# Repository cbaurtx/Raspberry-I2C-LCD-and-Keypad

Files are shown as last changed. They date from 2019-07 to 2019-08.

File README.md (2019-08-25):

# Raspberry-I2C-LCD-and-Keypad
LCD Display and Keypad controller connected to Raspberry Pi via i2c
KiCAD (http://www.kicad-pcb.org) is used for schematics and PCB layout

Connection to the Raspberry Pi:

RasPi pin | Keypad / LCD Signal|Description
----------|--------------------|-----------
2|5V|power
3|SCL|serial clock
6|SDG|serial ground / shield
5|SDA|serial data
6|GND|ground
12|INT|interrupt

You can populate the PCB partially if only the LCD display or the keypad
controller is needed.

Blockdiagramm
Overview schematics

Raspberry interface
Raspberry interface

Display:
Display controller

Keypad:
Keypad controller

Created using KiCAD 5.1.3
Conceived using information from: https://5volt-junkie.net/i2c-keypad/

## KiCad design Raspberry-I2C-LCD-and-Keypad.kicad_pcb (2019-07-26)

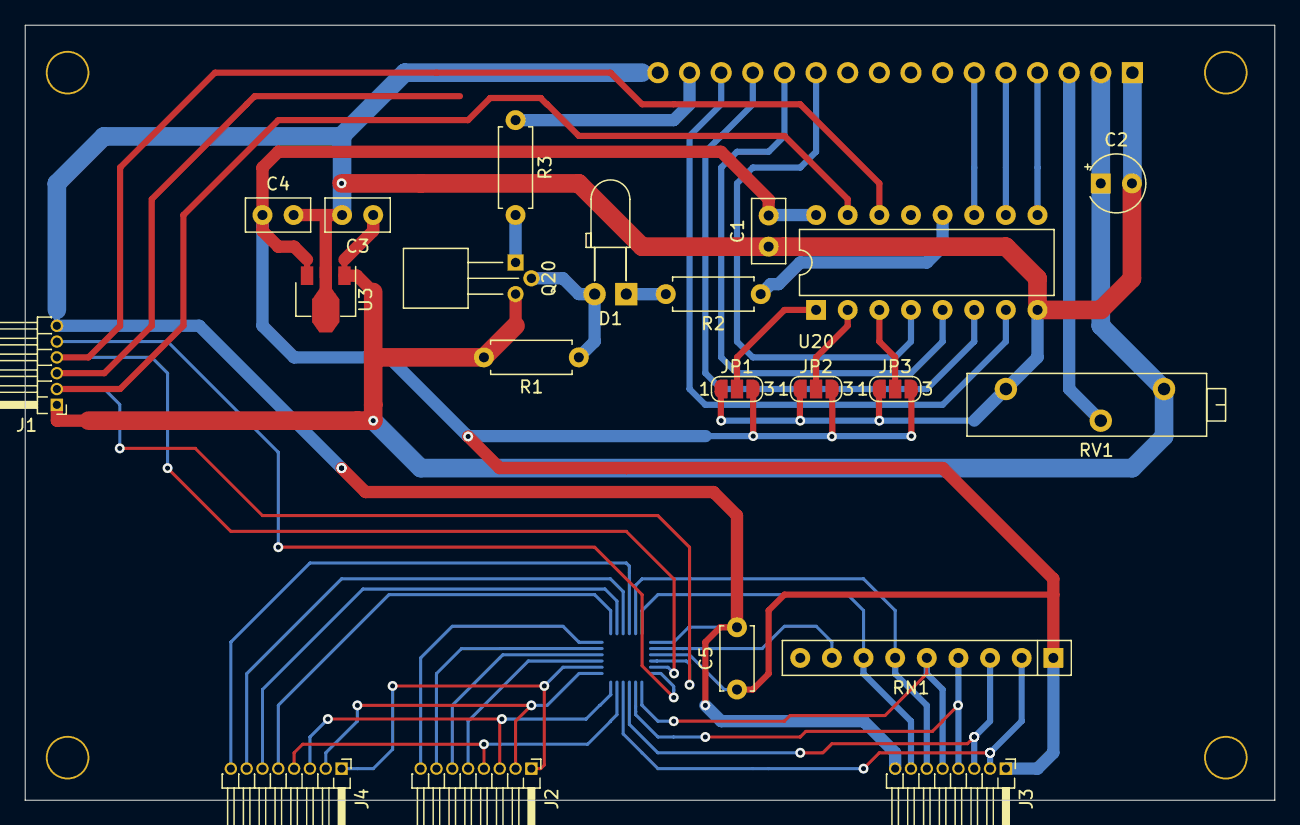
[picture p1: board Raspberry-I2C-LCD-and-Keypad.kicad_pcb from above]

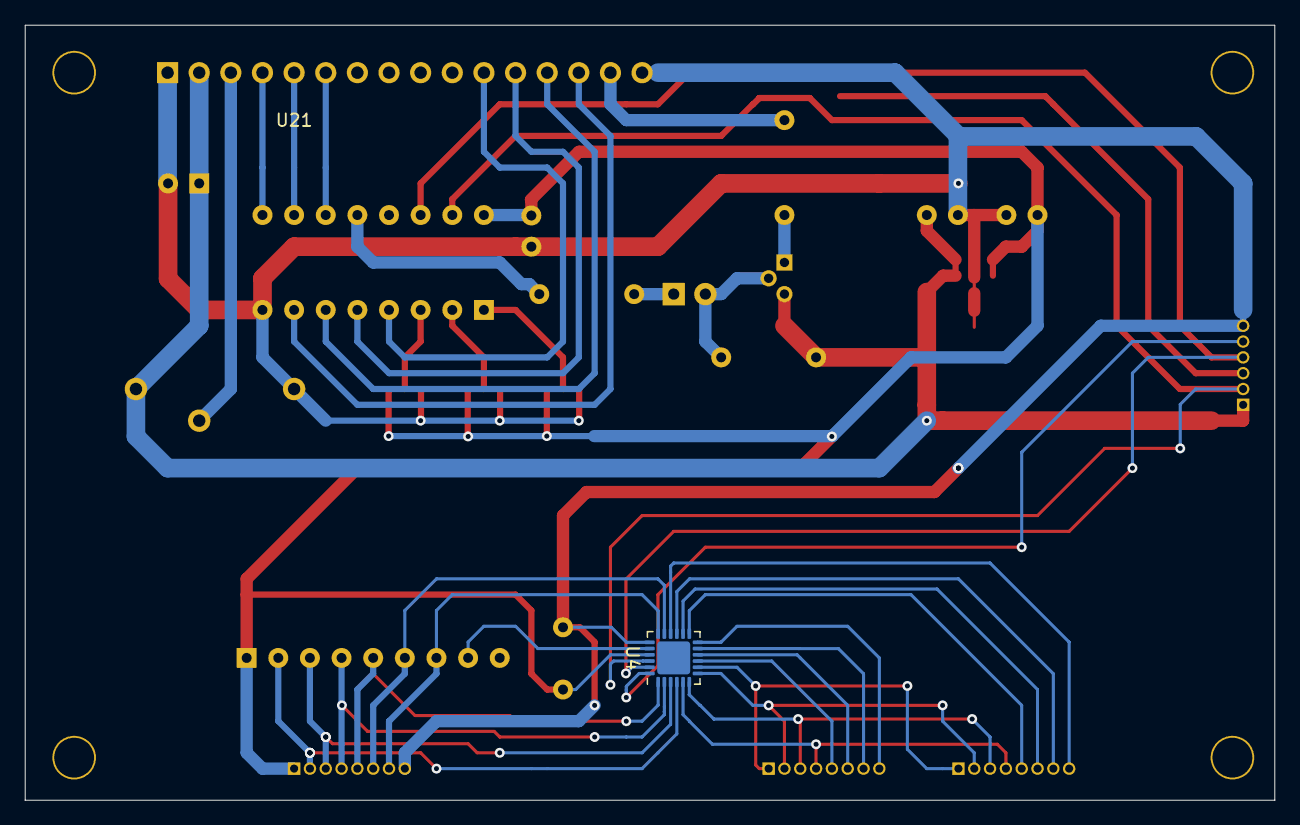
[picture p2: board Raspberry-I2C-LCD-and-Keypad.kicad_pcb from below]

Board: 2 copper layers, 100.3 x 62.2 mm, 23 parts (2 on the bottom side), 41 nets.

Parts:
C1, C3, C4: 100n; C_Disc_D5.0mm_W2.5mm_P2.50mm
C2: 10µ; CP_Radial_Tantal_D4.5mm_P2.50mm
C5: 100n; C_Disc_D5.0mm_W2.5mm_P5.00mm
D1: green; LED_D3.0mm_Horizontal_O3.81mm_Z2.0mm
J1: Conn_01x06; PinHeader_1x06_P1.27mm_Horizontal
J2, J3, J4: Conn_01x08; PinHeader_1x08_P1.27mm_Horizontal
JP1, JP2, JP3: Jumper_NC_Dual; SolderJumper-3_P1.3mm_Open_RoundedPad1.0x1.5mm_NumberLabels
Q20: BC557; TO-92_Horizontal1
R1: 4k7; R_Axial_DIN0207_L6.3mm_D2.5mm_P7.62mm_Horizontal
R2: 1k; R_Axial_DIN0207_L6.3mm_D2.5mm_P7.62mm_Horizontal
R3: 180; R_Axial_DIN0207_L6.3mm_D2.5mm_P7.62mm_Horizontal
RN1: 10k; R_Array_SIP9
RV1: 10k; Potentiometer_Vishay_43_Horizontal
U3: AP2204R-3.3; SOT-89-3
U4: TCA8418; QFN-24-1EP_4x4mm_P0.5mm_EP2.65x2.65mm
U20: PCF8574A; DIP-16_W7.62mm
U21: LCD_HD44780; QC2004A

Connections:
+3V3: C1.2, C4.1, C5.1, J3.1, JP1.3, JP2.3, JP3.3, RN1.1, U3.3, U4.21, U20.16
/DisplayController/5V: C2.1, C3.1, J1.1, Q20.3, R1.2, RV1.3, U3.1, U21.2
/DisplayController/GND: C1.1, C2.2, C3.2, C4.2, C5.2, J1.6, J3.8, JP1.1, JP2.1, JP3.1, RV1.1, U3.2, U4.19, U20.8, U21.1, U21.16
/DisplayController/SCL: J1.4, U4.23, U20.14
/DisplayController/SDA: J1.2, U4.22, U20.15
/KeypadController/~INT: J1.5, U4.24
/KeypadController/~RES: RN1.8, U4.20
unnamed: D1.1, R2.2
unnamed: D1.2, Q20.2, R1.1
unnamed: J2.1, J4.1, U4.8
unnamed: J2.2, J4.2, U4.7
unnamed: J2.3, J4.3, U4.6
unnamed: J2.4, J4.4, U4.5
unnamed: J2.5, U4.9
unnamed: J2.6, U4.10
unnamed: J2.7, U4.11
unnamed: J2.8, U4.12
unnamed: J3.2, RN1.2, U4.4
unnamed: J3.3, RN1.3, U4.3
unnamed: J3.4, RN1.4, U4.2
unnamed: J3.5, RN1.5, U4.1
unnamed: J3.6, RN1.6, U4.17
unnamed: J3.7, RN1.7, U4.18
unnamed: J4.5, U4.13
unnamed: J4.6, U4.14
unnamed: J4.7, U4.15
unnamed: J4.8, U4.16
unnamed: JP1.2, U20.1
unnamed: JP2.2, U20.2
unnamed: JP3.2, U20.3
unnamed: Q20.1, R3.2
unnamed: R2.1, U20.12
unnamed: R3.1, U21.15
unnamed: RV1.2, U21.3
unnamed: U20.4, U21.11
unnamed: U20.5, U21.12
unnamed: U20.6, U21.13
unnamed: U20.7, U21.14
unnamed: U20.9, U21.4
unnamed: U20.10, U21.5
unnamed: U20.11, U21.6

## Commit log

2019-07-25 new file: DisplayController.sch new file: KeypadController.sch new file: RasPiInterface.bck new file: RasPiInterface.dcm new file: RasPiInterface.lib new file: RasPiInterface.sch new file: Raspberry-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
    [DisplayController.sch, KeypadController.sch, RasPiInterface.sch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]
2019-07-26 modified: DisplayController.sch modified: KeypadController.sch new file: QC2004A.kicad_mod modified: RasPiInterface.lib modified: RasPiInterface.sch new file: Raspberry-I2C-LCD-and-Keypad-B_Cu.gbr ne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
    [DisplayController.sch, KeypadController.sch, RasPiInterface.sch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]
2019-07-26 modified: QC2004A.kicad_mod deleted: RasPiInterface.bck deleted: RasPiInterface.dcm modified: RasPiInterface.lib deleted: Raspberry-I2C-LCD-and-Keypad-B_Paste.gbr deleted: Raspberry-I2C-LCD-and-Keypa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
    [Raspberry-I2C-LCD-and-Keypad-B_Cu.gbr, Raspberry-I2C-LCD-and-Keypad-B_Mask.gbr, Raspberry-I2C-LCD-and-Keypad-Edge_Cuts.gbr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]
2019-07-26 modified: Raspberry-I2C-LCD-and-Keypad.kicad_pcb new file: build/Raspberry-I2C-LCD-and-Keypad-B_Cu.gbr new file: build/Raspberry-I2C-LCD-and-Keypad-B_Mask.gbr new file: build/Raspberry-I2C-LCD-and-Ke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
    [Raspberry-I2C-LCD-and-Keypad-B_Cu.gbr, Raspberry-I2C-LCD-and-Keypad-B_Mask.gbr, Raspberry-I2C-LCD-and-Keypad-B_Paste.gbr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]
2019-07-26 deleted: Raspberry-I2C-LCD-and-Keypad.kicad_pcb-bak
2019-07-26 deleted: build/Raspberry-I2C-LCD-and-Keypad-B_Cu.gbr deleted: build/Raspberry-I2C-LCD-and-Keypad-B_Mask.gbr deleted: build/Raspberry-I2C-LCD-and-Keypad-F_Cu.gbr deleted: build/Raspberry-I2C-LCD-and-K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
    [Raspberry-I2C-LCD-and-Keypad-B_Cu.gbr, Raspberry-I2C-LCD-and-Keypad-B_Mask.gbr, Raspberry-I2C-LCD-and-Keypad-B_Paste.gbr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]
2019-08-25 modified: README.md new file: doc/DisplayController.svg new file: doc/KeypadController.svg new file: doc/RasPiInterface.svg new file: doc/Raspberry-I2C-LCD-and-Keypad.svg renamed: gerber/Raspberry-I2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
    [Raspberry-I2C-LCD-and-Keypad-B_Cu.gbl, Raspberry-I2C-LCD-and-Keypad-B_Cu.gbr, Raspberry-I2C-LCD-and-Keypad-B_Mask.gbs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]
2019-10-05 new file: "Ras\303\274berry-I2C-cable-cache.lib" new file: "Ras\303\274berry-I2C-cable.pro" new file: "Ras\303\274berry-I2C-cable.sch" new file: doc/GPIOpinout_RB2b.fodt modified: fp-info-cache delet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
    [Rasüberry-I2C-cable.sch]
